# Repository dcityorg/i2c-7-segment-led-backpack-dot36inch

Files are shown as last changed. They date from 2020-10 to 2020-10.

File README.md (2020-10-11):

#### I²C 7 Segment LED Backpack Board (.36 inch LEDs)

<div style="text-align: center;">
<div style="display: inline-block; margin-right: 5px;">

</div>
<div style="display: inline-block; margin-right: 5px;">

</div>
<div style="display: inline-block; margin-right: 5px;">

</div>
</div>

**[This link has details](https://www.dcity.org/portfolio/i2c-7-segment-led-backpack-dot36inch/) including**
* parts lists
* assembly instructions
* jumper configuration
* Arduino, Particle and Raspberry Pi software library usage
* Bare PC boards are available from OSHPark.

**Note: The pictures show the backpack board with Grove type connectors, but they have been changed to [Qwiic](https://www.sparkfun.com/qwiic) connectors.**

**License Information**
Open Source Hardware Design. Our License Information is [here](https://www.dcity.org/license-information/).

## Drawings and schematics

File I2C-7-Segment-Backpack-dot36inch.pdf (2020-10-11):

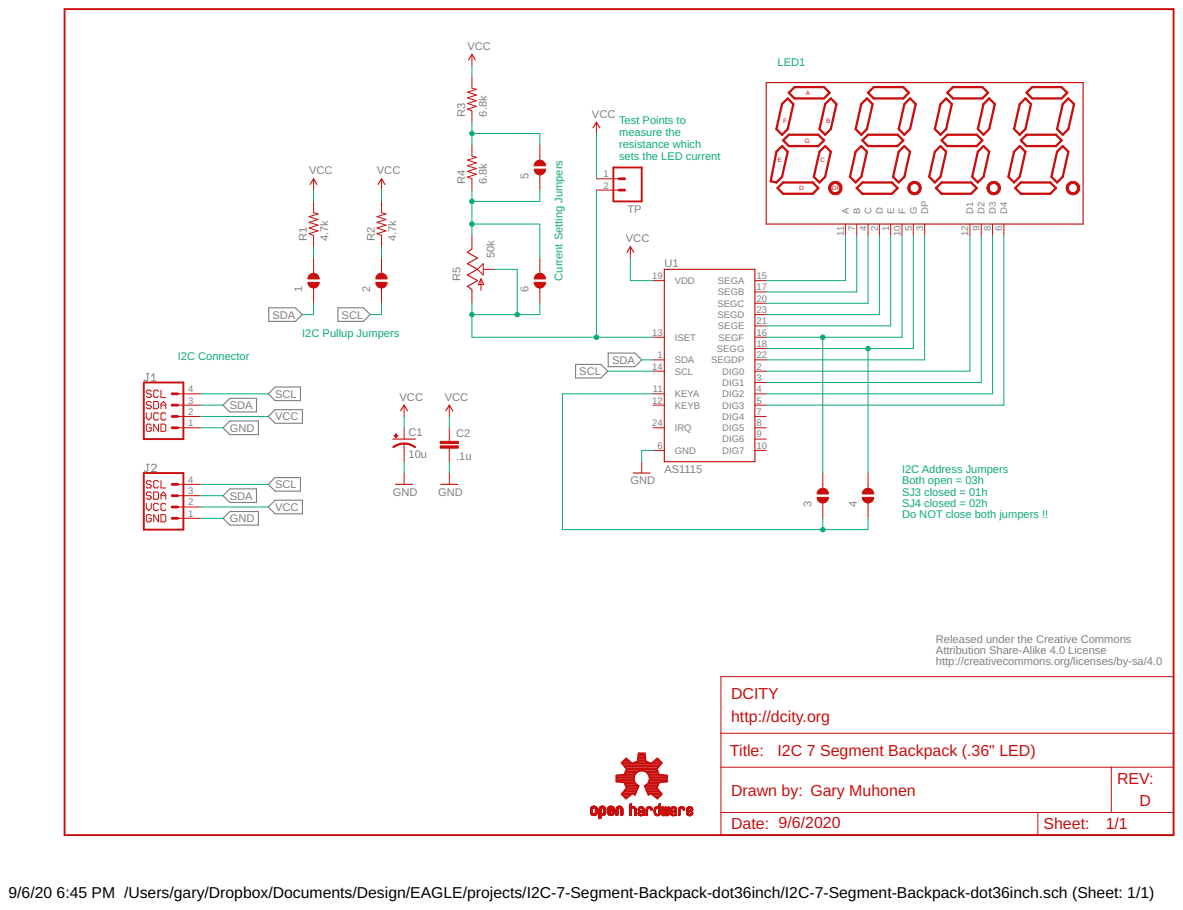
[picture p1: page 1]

VCC
Test Points to measure the
resistance which
sets the LED current

I2C Address Jumpers Both open = 03h
SJ3 closed = 01h
SJ4 closed = 02h
Do NOT close both jumpers !!

Released under the Creative Commons http://creativecommons.org/licenses/by-sa/4.0
Attribution Share-Alike 4.0 License

Drawn by: | REV: D Gary Muhonen

Date: 9/6/2020 | Sheet: 1/1

9/6/20 6:45 PM /Users/gary/Dropbox/Documents/Design/EAGLE/projects/I2C-7-Segment-Backpack-dot36inch/I2C-7-Segment-Backpack-dot36inch.sch (Sheet: 1/1)

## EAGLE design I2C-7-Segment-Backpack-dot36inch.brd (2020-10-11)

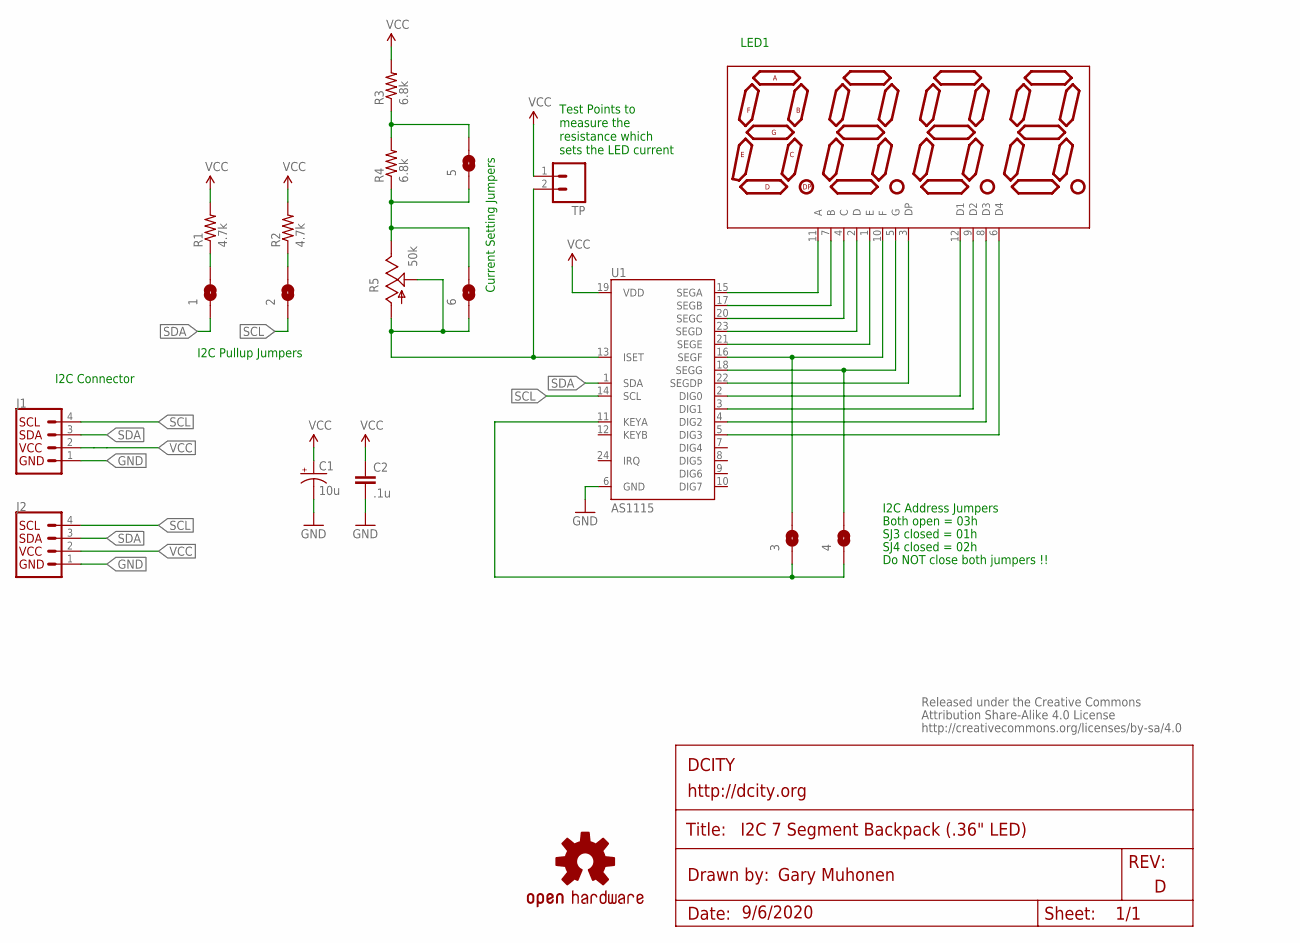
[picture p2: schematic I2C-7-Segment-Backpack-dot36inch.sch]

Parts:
1, 2, 3, 4, 5, 6: SOLDERJUMPERNO; SJ_2S-NO
C1: 10u; 0805-POL
C2: .1u; 0805-CAP
DISP1: LED1; 7-SEGMENT-4DIGIT-PT4
J1, J2: QWIIC_RIGHT_ANGLE; JST04_1MM_RA
LOGO1: OSHW-LOGOS; OSHW-LOGO-S
R1, R2: 4.7k; 0805-RES
R3, R4: 6.8k; 0805-RES
R5: 50k; POT-TC33X
TP: M02PTH; 1X02
U1: AS1115; TSSOP24-NO-HS
U$4: CREATIVE_COMMONS

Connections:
GND: C1.-, C2.2, J1.1, J2.1, U1.6 (GND)
unnamed: DISP1.11 (A), U1.15 (SEGA)
unnamed: DISP1.7 (B), U1.17 (SEGB)
unnamed: DISP1.4 (C), U1.20 (SEGC)
unnamed: DISP1.2 (D), U1.23 (SEGD)
unnamed: DISP1.1 (E), U1.21 (SEGE)
unnamed: 3.2, DISP1.10 (F), U1.16 (SEGF)
unnamed: 4.2, DISP1.5 (G), U1.18 (SEGG)
unnamed: DISP1.3 (DP), U1.22 (SEGDP)
unnamed: DISP1.12 (D1), U1.2 (DIG0)
unnamed: DISP1.9 (D2), U1.3 (DIG1)
unnamed: DISP1.8 (D3), U1.4 (DIG2)
unnamed: DISP1.6 (D4), U1.5 (DIG3)
unnamed: 3.1, 4.1, U1.11 (KEYA)
unnamed: 6.1, R5.1 (A), R5.2 (S), TP.2, U1.13 (ISET)
unnamed: 5.1, 6.2, R4.1, R5.3 (E)
unnamed: 5.2, R3.1, R4.2
unnamed: 1.2, R1.1
unnamed: 2.2, R2.1
SCL: 2.1, J1.4, J2.4, U1.14 (SCL)
SDA: 1.1, J1.3, J2.3, U1.1 (SDA)
VCC: C1.+, C2.1, J1.2, J2.2, R1.2, R2.2, R3.2, TP.1, U1.19 (VDD)

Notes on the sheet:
I2C Connector
I2C Pullup Jumpers
Current Setting Jumpers
I2C Address Jumpers
Both open = 03h
SJ3 closed = 01h
SJ4 closed = 02h
Do NOT close both jumpers !!
LED1
Test Points to measure the resistance which sets the LED current

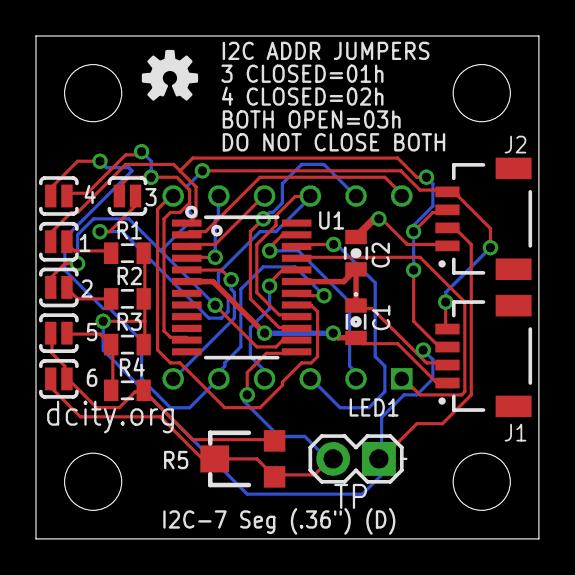
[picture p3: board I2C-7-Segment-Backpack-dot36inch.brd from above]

Board: 2 copper layers, 27.9 x 27.9 mm, 20 parts (1 on the bottom side), 22 nets.

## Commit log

2016-07-30 First commit - Rev B
    [I2C-7-Segment-Backpack-dot36inch.brd, I2C-7-Segment-Backpack-dot36inch.sch]
2018-09-14 Rev C
    [I2C-7-Segment-Backpack-dot36inch.brd, I2C-7-Segment-Backpack-dot36inch.sch]
2020-10-11 Rev D
    [I2C-7-Segment-Backpack-dot36inch.brd, I2C-7-Segment-Backpack-dot36inch.sch]
